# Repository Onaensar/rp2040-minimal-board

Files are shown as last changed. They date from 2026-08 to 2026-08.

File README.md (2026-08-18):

# ⚡ MDC RP2040 - Custom 4-Layer Development Board

A compact, industrial-standard 4-layer custom microcontroller development board powered by the **Raspberry Pi RP2040**. Built for high signal integrity, low-noise power distribution, and full hardware ESD protection.

---

## 📸 Hardware Overview

| Top View | Bottom View |
| :---: | :---: |
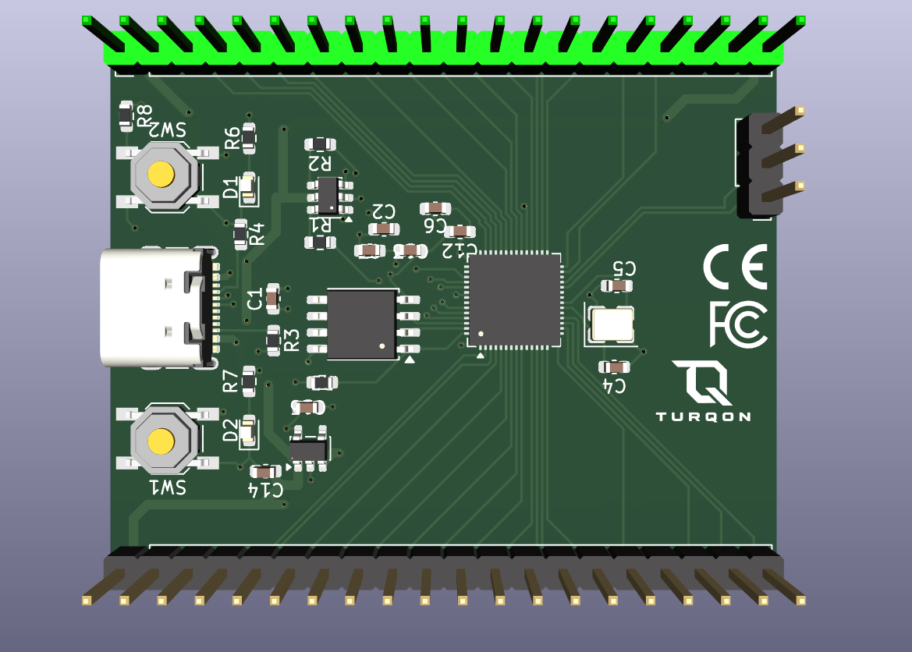
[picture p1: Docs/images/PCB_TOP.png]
Board Top
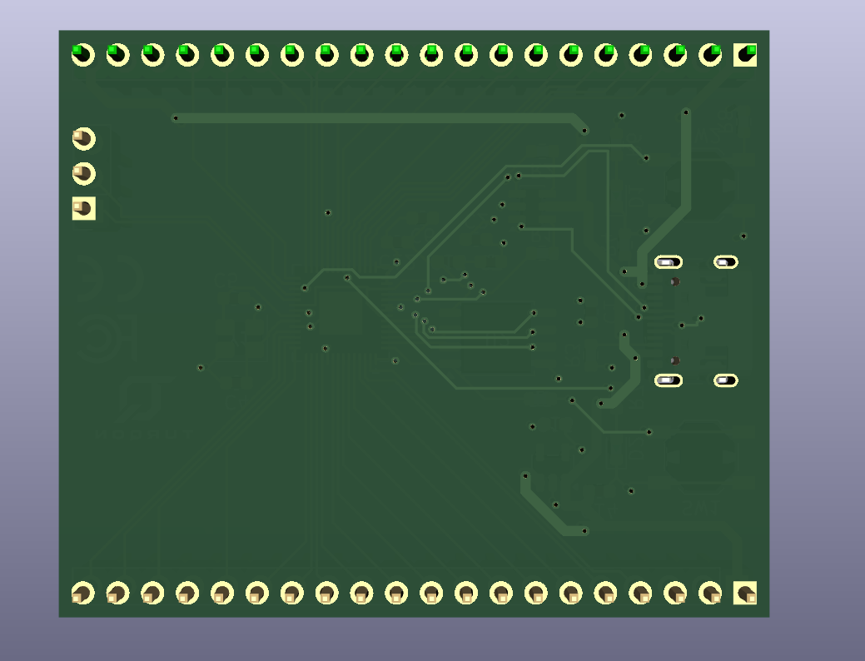
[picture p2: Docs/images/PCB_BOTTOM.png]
Board Bottom
|  |  |

---

## 🛠 Key Hardware Specifications

* **Microcontroller:** Raspberry Pi RP2040 (Dual ARM Cortex-M0+ @ 133 MHz, 264 KB SRAM)
* **Flash Memory:** 16 MB (128 Mb) Winbond QSPI Flash (`W25Q128JVSIQ`)
* **Power Regulation:**
  * High-performance 600 mA 3.3V LDO regulator (`AP2112K-3.3`)
  * Low ESR ceramic decoupling network across all internal power rails (`DVDD 1.1V`, `IOVDD 3.3V`, `ADC_AVDD 3.3V`)
* **USB Interface:** USB Type-C 2.0 with dedicated ESD protection (`USBLC6-2SC6`) and dual 5.1 kΩ CC configuration resistors
* **Clock System:** 12 MHz surface-mount crystal oscillator with dedicated symmetrical load capacitor array (`27 pF`) and isolated ground shielding
* **I/O & Peripherals:**
  * Standard 2.54 mm dual-row pinout exposing 30 multi-function GPIOs (SPI, I2C, UART, PWM, ADC)
  * Dedicated 3-pin SWD interface (`SWCLK`, `SWDIO`, `GND`) for debug probes (Picoprobe / J-Link)
  * Hardware `BOOT` and `RESET` pushbuttons
  * Status LEDs for `Power` (+3.3V) and user-programmable indicator (`GPIO25`)

---

## 📐 PCB Layer Stack-up (4-Layer FR-4)

Designed adhering to standard 1.6 mm PCB manufacturing guidelines (e.g., JLCPCB JLC04161H / PCBWay):

| Layer | Type | Copper Thickness | Function / Allocation |
| :--- | :--- | :--- | :--- |
| **Layer 1 (F.Cu)** | Signal | 1.0 oz (35 µm) | Core ICs, high-speed USB differential pairs, QSPI routing, and local decoupling loops |
| **Layer 2 (In1.Cu)** | Plane | 0.5 oz (17.5 µm) | **Unbroken Solid Ground Plane (GND)** for optimal return path and EMI shielding |
| **Layer 3 (In2.Cu)** | Power | 0.5 oz (17.5 µm) | Dedicated **+3.3V & +1.1V Power Planes** |
| **Layer 4 (B.Cu)** | Signal / GND | 1.0 oz (35 µm) | Low-speed signal breakout paths with unbroken ground copper pour |

---

## 📁 Repository Structure

```text
├── docs/                   # Renderings, hardware design schematics (PDF), and pinout guides
│   └── images/             # 3D PCB board renders
├── hardware/               # KiCad project files (.kicad_pro, .kicad_sch, .kicad_pcb)
├── manufacturing/          # Production-ready Gerbers, Drill files, BOM, and CPL files
├── .gitignore              # KiCad workspace exclusion rules
└── README.md

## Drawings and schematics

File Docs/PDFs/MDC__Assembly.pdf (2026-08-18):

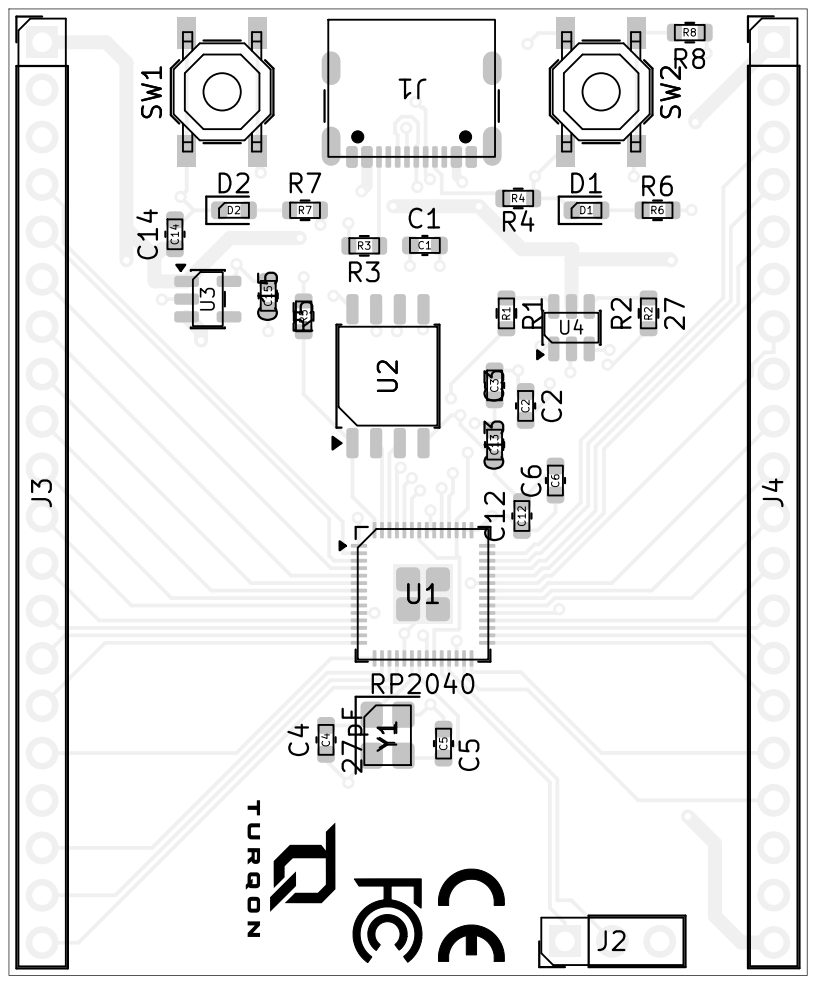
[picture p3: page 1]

MCU: RP2040 Dual ARM Cortex-M0+ | 16MB QSPI Flash
Architecture: 4-Layer FR-4 (JLC04161H Stackup)
Designed by: Abdullah Ensar Ön
TURQON
Sheet: Black And White TOP
File: MDC.kicad_pcb
Title: MDC RP2040 Minimal Dev Board
KiCad E.D.A. 10.0.4

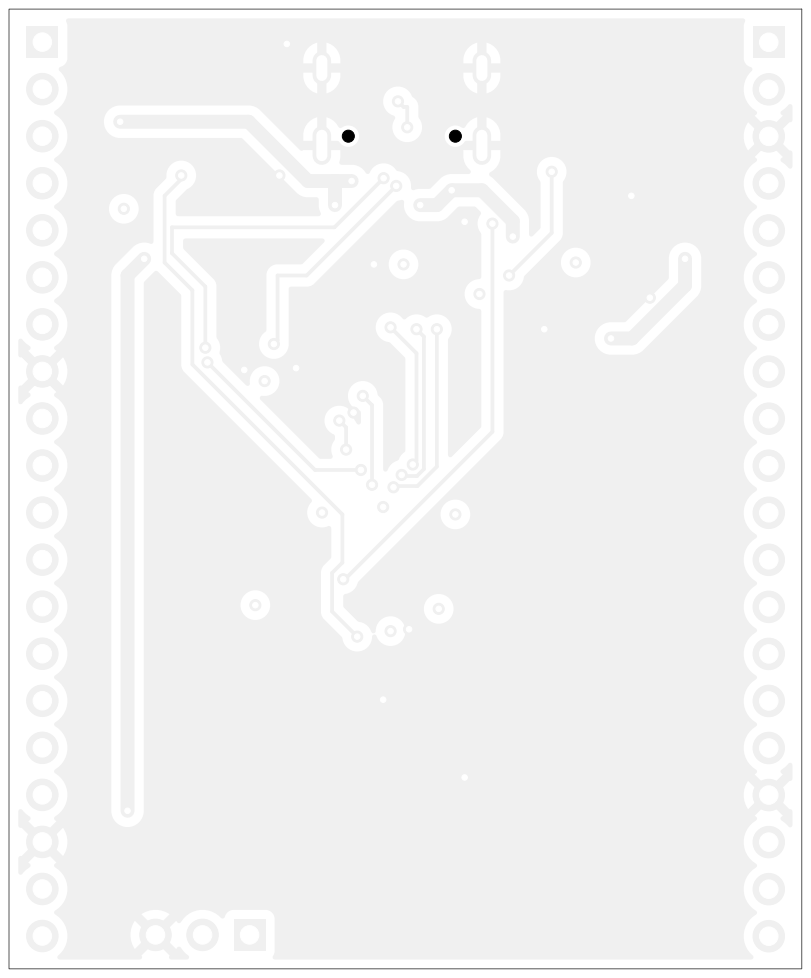
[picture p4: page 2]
D Date: 2026-08-18

Board2Pdf: Black And White BOT - Page 2/8
MCU: RP2040 Dual ARM Cortex-M0+ | 16MB QSPI Flash
Architecture: 4-Layer FR-4 (JLC04161H Stackup)
Designed by: Abdullah Ensar Ön
TURQON
Sheet: Black And White BOT
File: MDC.kicad_pcb
Title: MDC RP2040 Minimal Dev Board

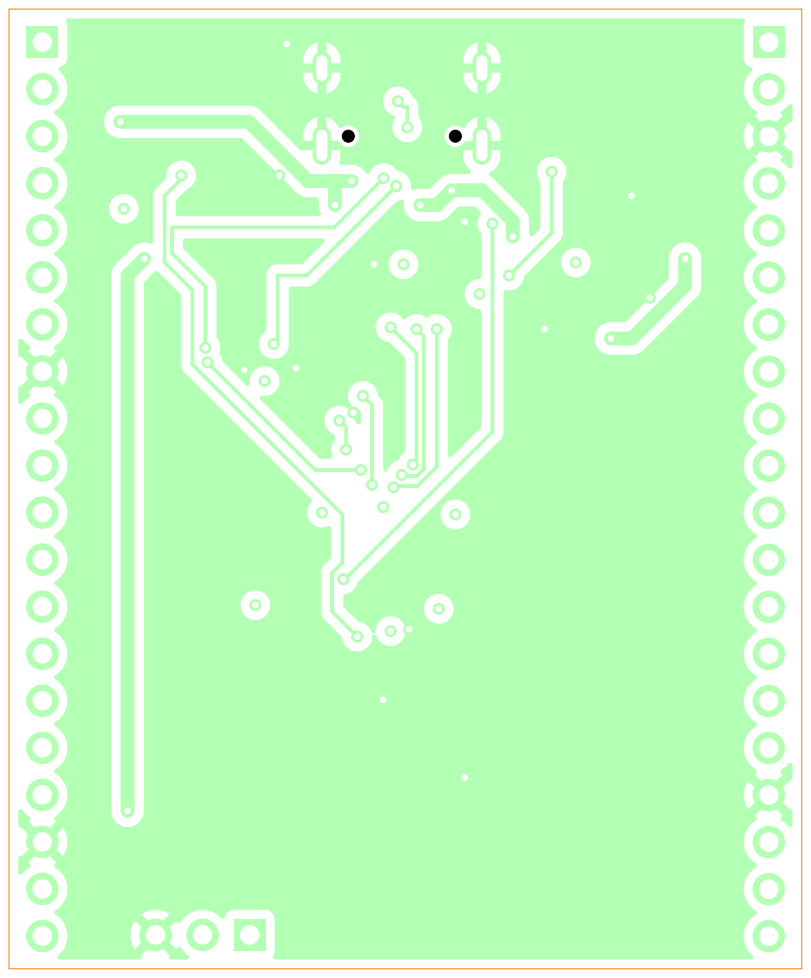
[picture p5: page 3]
D Date: 2026-08-18

Board2Pdf: Colored BOT - Page 3/8
MCU: RP2040 Dual ARM Cortex-M0+ | 16MB QSPI Flash
Architecture: 4-Layer FR-4 (JLC04161H Stackup)
Designed by: Abdullah Ensar Ön
TURQON
Sheet: Colored BOT
File: MDC.kicad_pcb
Title: MDC RP2040 Minimal Dev Board

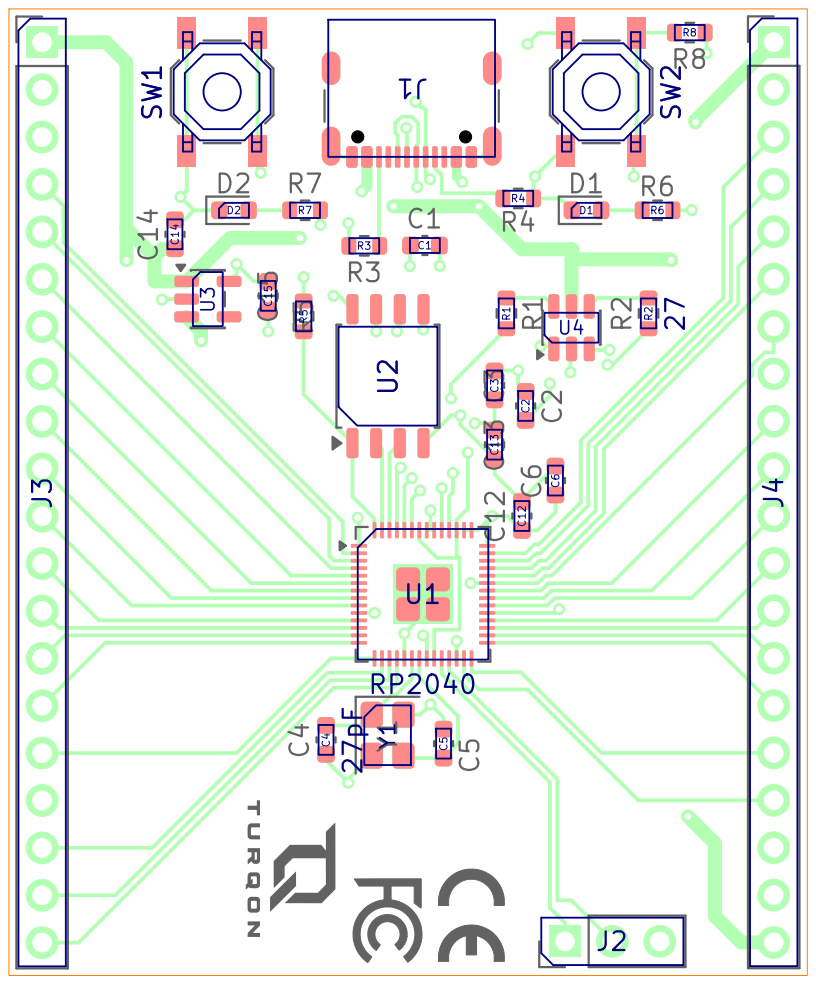
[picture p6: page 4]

MCU: RP2040 Dual ARM Cortex-M0+ | 16MB QSPI Flash
Architecture: 4-Layer FR-4 (JLC04161H Stackup)
Designed by: Abdullah Ensar Ön
TURQON
Sheet: Colored TOP
File: MDC.kicad_pcb
Title: MDC RP2040 Minimal Dev Board

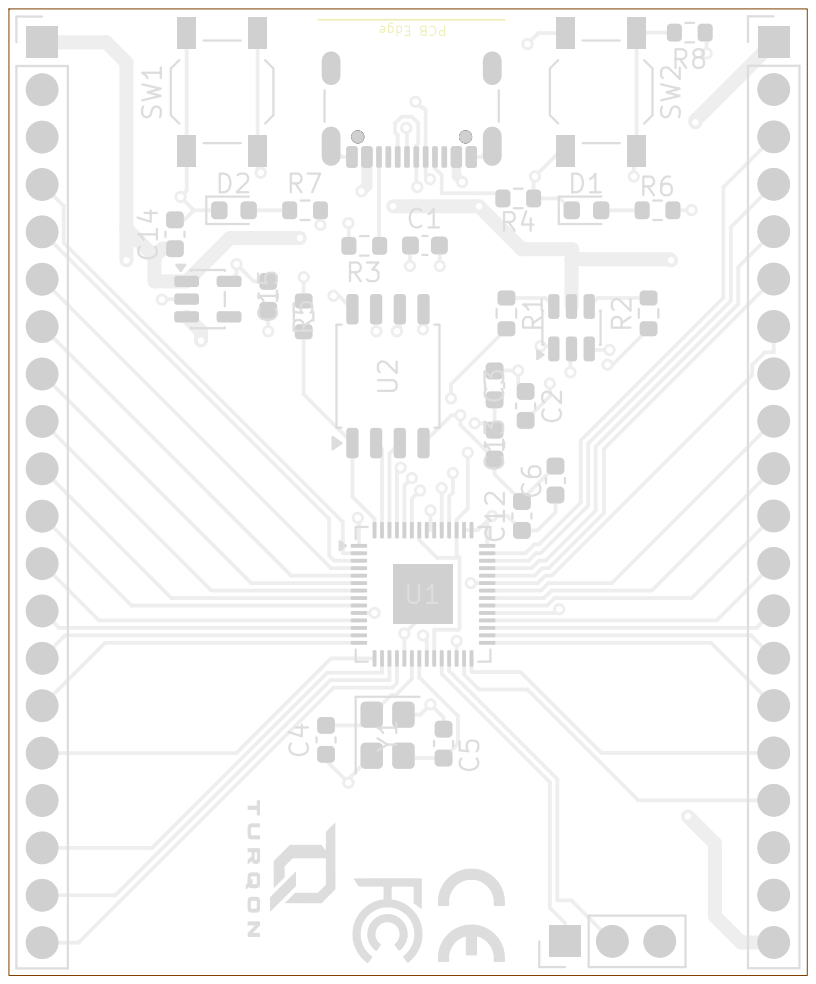
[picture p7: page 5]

Board2Pdf: Light Colors PCB Fabrication TOP - Page 5/8
MCU: RP2040 Dual ARM Cortex-M0+ | 16MB QSPI Flash
Architecture: 4-Layer FR-4 (JLC04161H Stackup)
Designed by: Abdullah Ensar Ön
TURQON
Sheet: Light Colors PCB Fabrication TOP
File: MDC.kicad_pcb
Title: MDC RP2040 Minimal Dev Board

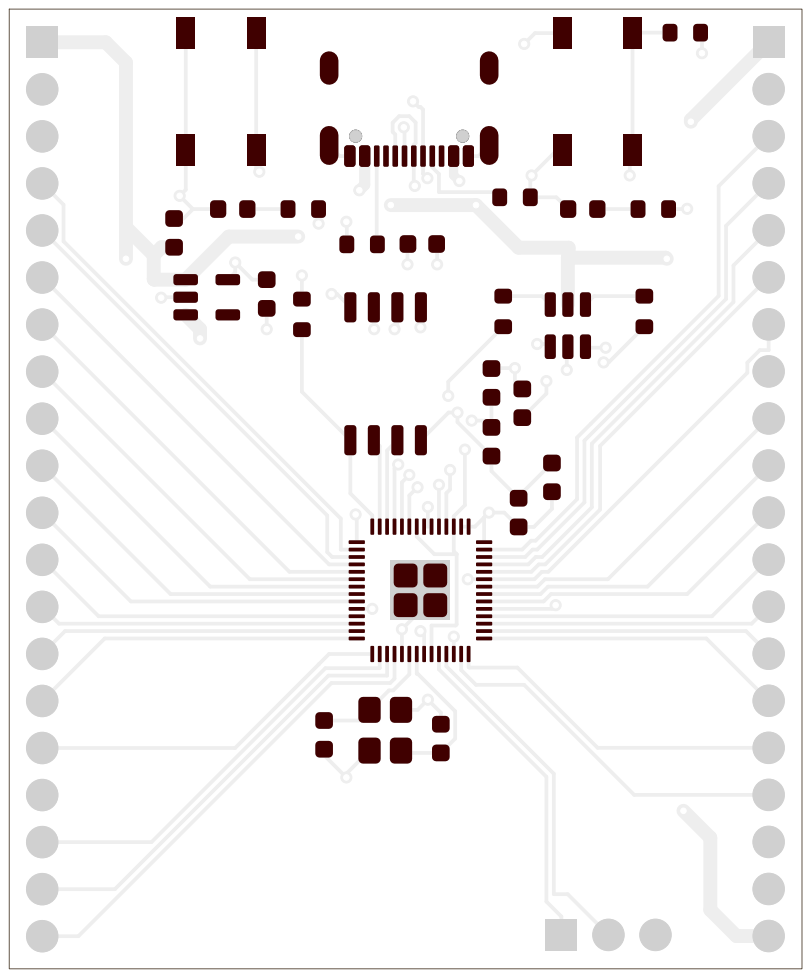
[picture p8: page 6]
D Date: 2026-08-18

Board2Pdf: Light Colors PCB Paste TOP - Page 6/8
MCU: RP2040 Dual ARM Cortex-M0+ | 16MB QSPI Flash
Architecture: 4-Layer FR-4 (JLC04161H Stackup)
Designed by: Abdullah Ensar Ön
TURQON
Sheet: Light Colors PCB Paste TOP
File: MDC.kicad_pcb
Title: MDC RP2040 Minimal Dev Board

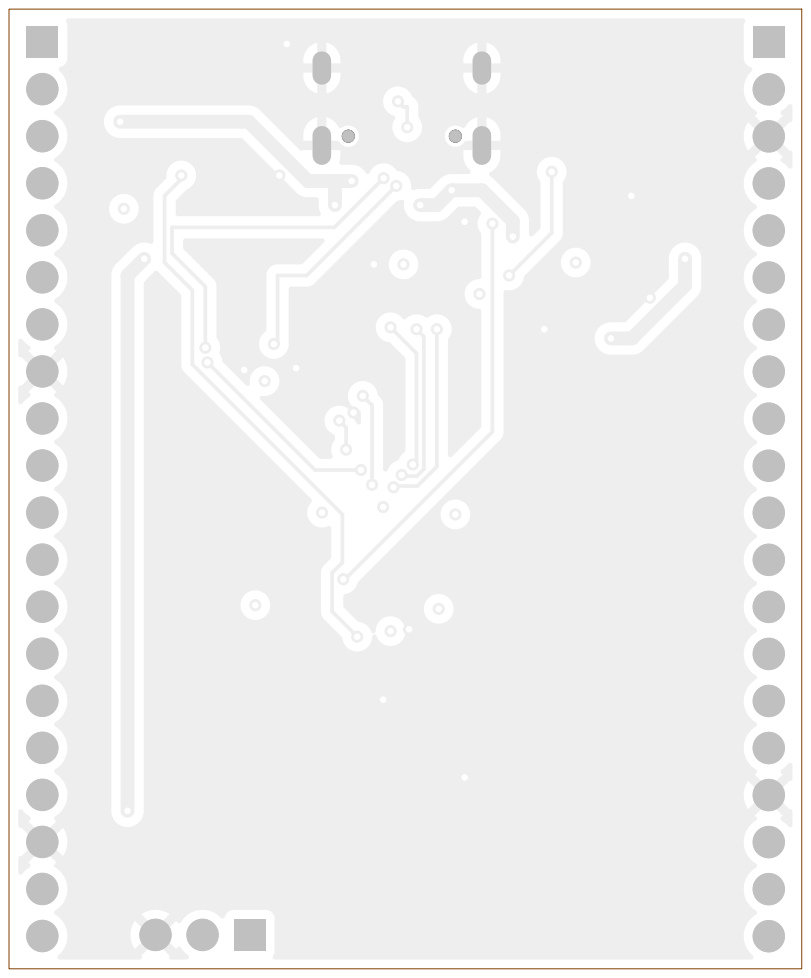
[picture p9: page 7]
D Date: 2026-08-18

Board2Pdf: Light Colors Placement BOT - Page 7/8
MCU: RP2040 Dual ARM Cortex-M0+ | 16MB QSPI Flash
Architecture: 4-Layer FR-4 (JLC04161H Stackup)
Designed by: Abdullah Ensar Ön
TURQON
Sheet: Light Colors Placement BOT
File: MDC.kicad_pcb
Title: MDC RP2040 Minimal Dev Board

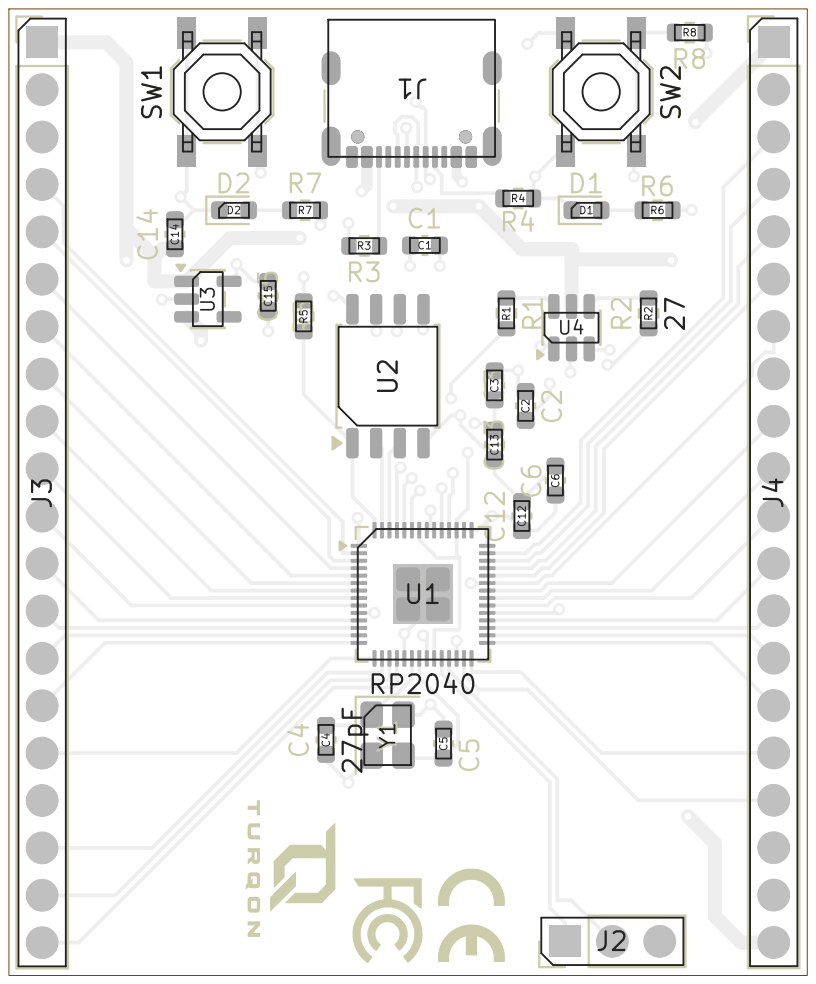
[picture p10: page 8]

Board2Pdf: Light Colors Placement TOP - Page 8/8
MCU: RP2040 Dual ARM Cortex-M0+ | 16MB QSPI Flash
Architecture: 4-Layer FR-4 (JLC04161H Stackup)
Designed by: Abdullah Ensar Ön
TURQON
Sheet: Light Colors Placement TOP
File: MDC.kicad_pcb
Title: MDC RP2040 Minimal Dev Board

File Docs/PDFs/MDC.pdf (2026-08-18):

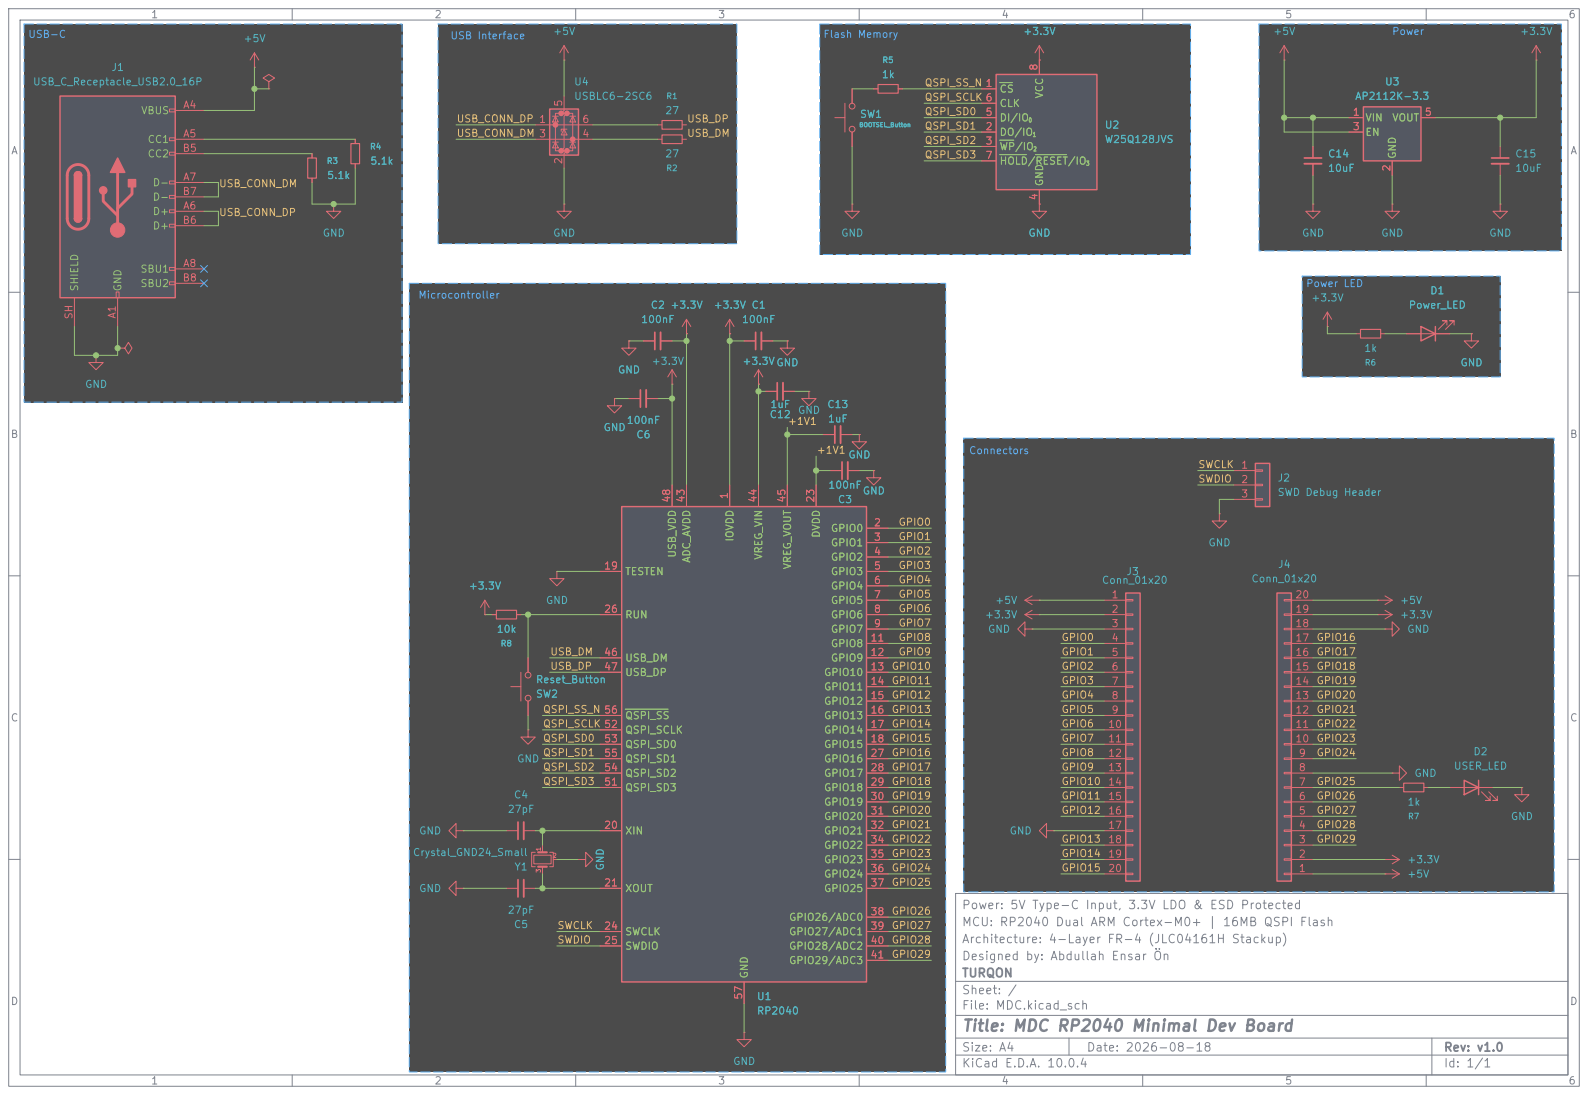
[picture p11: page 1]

4 DI/IO0 5 CLK 6 HOLD/RESET/IO3 7 VCC

MCU: RP2040 Dual ARM Cortex-M0+ | 16MB QSPI Flash
Architecture: 4-Layer FR-4 (JLC04161H Stackup)
Designed by: Abdullah Ensar Ön
TURQON
Sheet: /
File: MDC.kicad_sch
Title: MDC RP2040 Minimal Dev Board

Size: A4 | Rev: v1.0
KiCad E.D.A. 10.0.4 | Id: 1/1

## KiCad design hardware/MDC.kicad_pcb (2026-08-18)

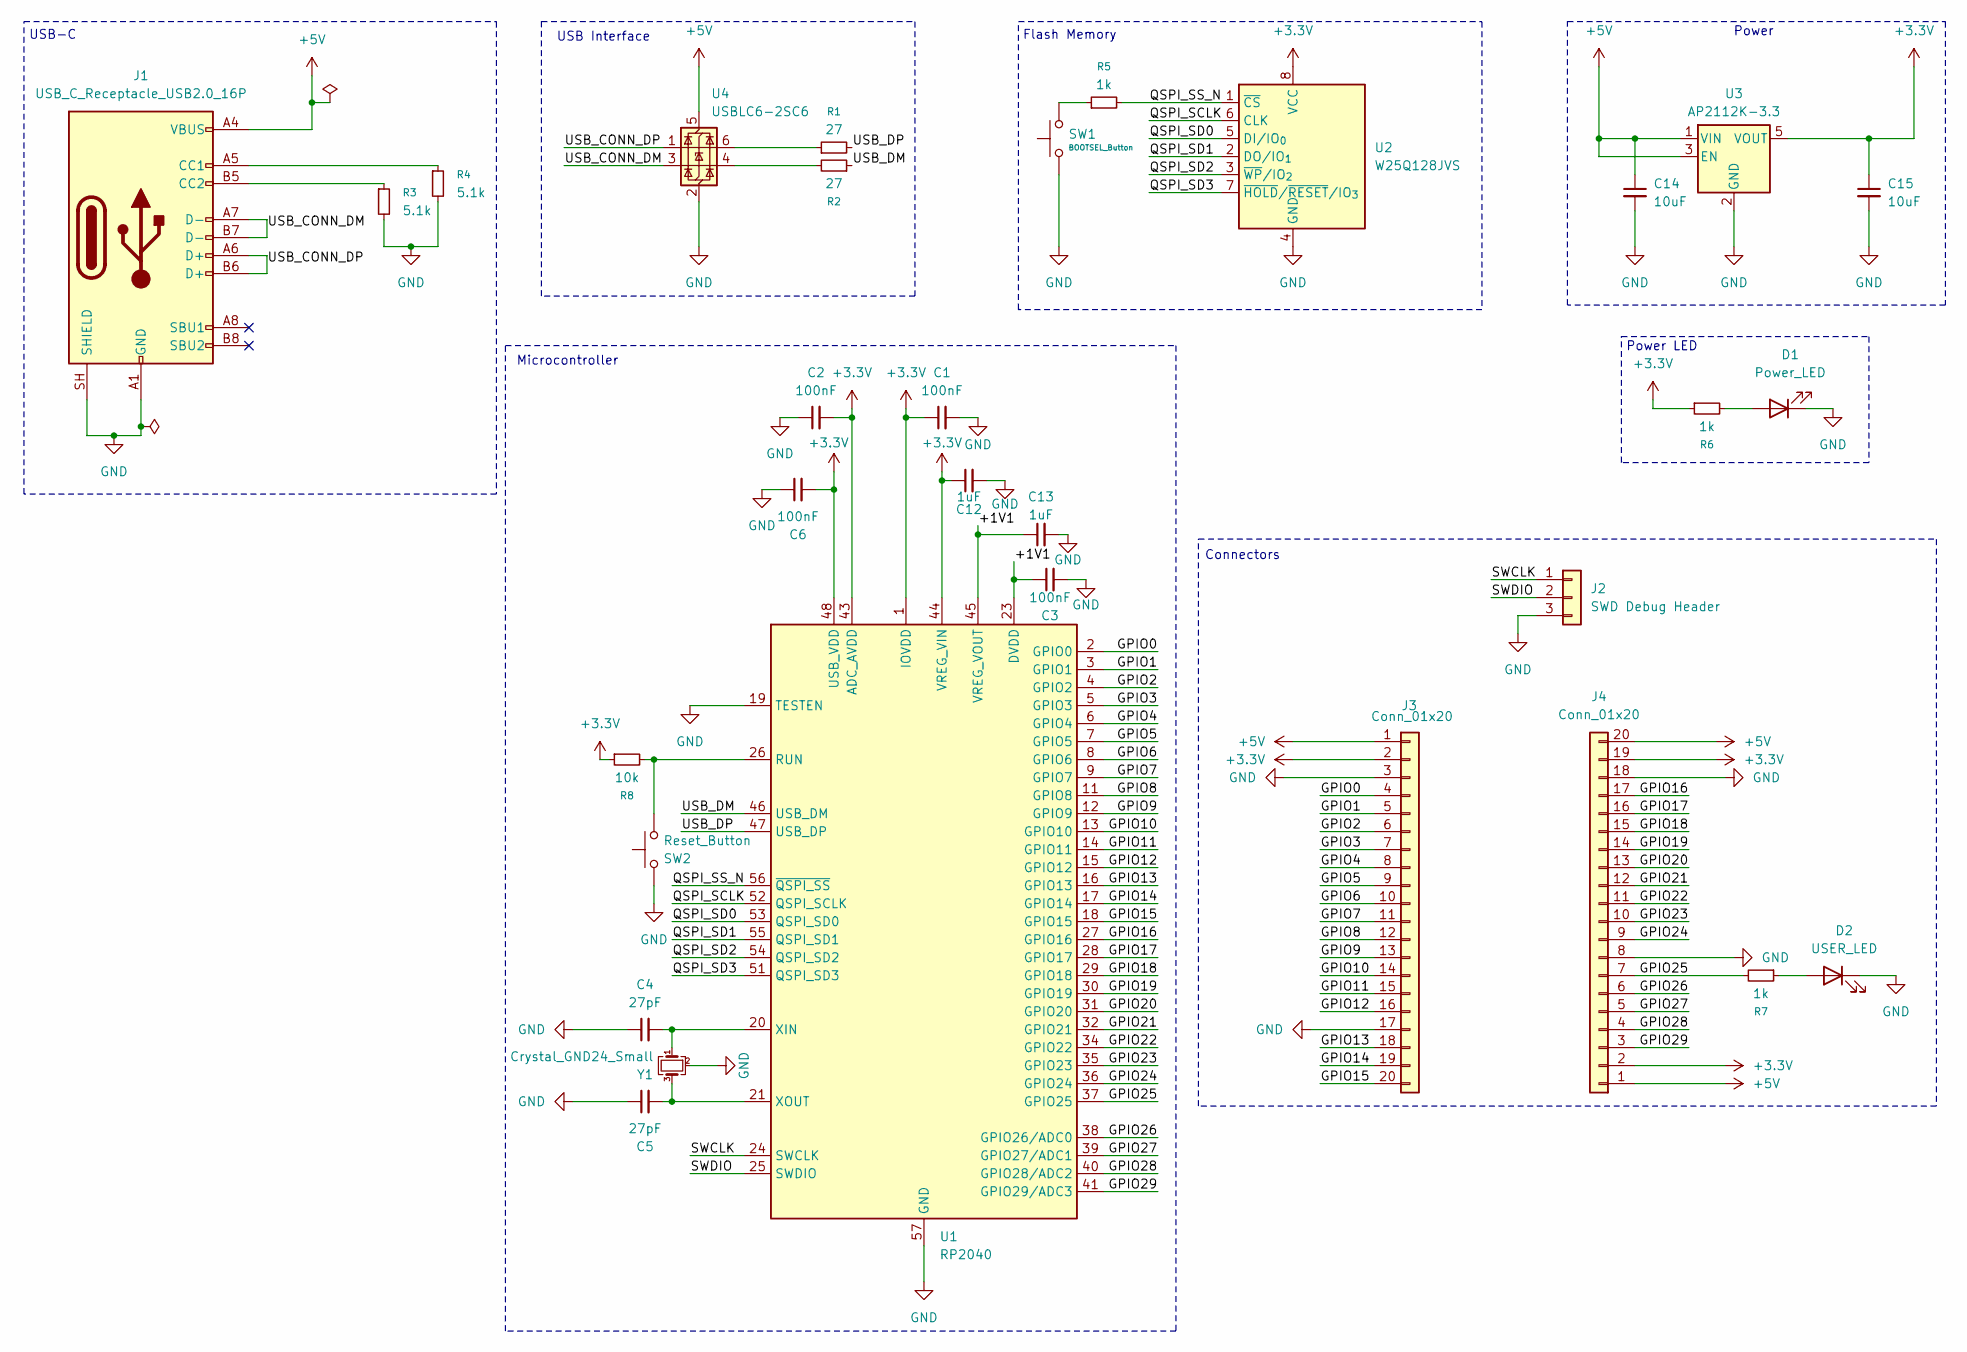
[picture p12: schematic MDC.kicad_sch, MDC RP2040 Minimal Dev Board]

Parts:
C1, C2, C3, C6: 100nF; C_0603_1608Metric
C4, C5: 27pF; C_0603_1608Metric
C12, C13: 1uF; C_0603_1608Metric
C14, C15: 10uF; C_0603_1608Metric
D1: Power_LED; LED_0603_1608Metric
D2: USER_LED; LED_0603_1608Metric
J1: USB_C_Receptacle_USB2.0_16P; USB_C_Receptacle_GCT_USB4105-xx-A_16P_TopMnt_Horizontal
J2: SWD Debug Header; PinHeader_1x03_P2.54mm_Vertical
J3, J4: Conn_01x20; PinHeader_1x20_P2.54mm_Vertical
R1, R2: 27; R_0603_1608Metric
R3, R4: 5.1k; R_0603_1608Metric
R5, R6, R7: 1k; R_0603_1608Metric
R8: 10k; R_0603_1608Metric
SW1: BOOTSEL_Button; SW_SPST_TL3342
SW2: Reset_Button; SW_SPST_TL3342
U1: RP2040; QFN-56-1EP_7x7mm_P0.4mm_EP3.2x3.2mm
U2: W25Q128JVS; SOIC-8_5.3x5.3mm_P1.27mm
U3: AP2112K-3.3; SOT-23-5
U4: USBLC6-2SC6; SOT-23-6
Y1: Crystal_GND24_Small; Crystal_SMD_3225-4Pin_3.2x2.5mm

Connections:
+3.3V: C1.1, C2.2, C6.2, C12.1, C15.1, J3.2, J4.2, J4.19, R6.1, R8.1, U1.1 (IOVDD), U1.10 (IOVDD), U1.22 (IOVDD), U1.33 (IOVDD), U1.42 (IOVDD), U1.43 (ADC_AVDD), U1.44 (VREG_VIN), U1.48 (USB_VDD), U1.49 (IOVDD), U2.8 (VCC), U3.5 (VOUT)
+5V: C14.1, J1.A4 (VBUS), J1.A9 (VBUS), J1.B4 (VBUS), J1.B9 (VBUS), J3.1, J4.1, J4.20, U3.1 (VIN), U3.3 (EN), U4.5 (VBUS)
/+1V1: C3.1, C13.1, U1.23 (DVDD), U1.45 (VREG_VOUT), U1.50 (DVDD)
/GPIO0: J3.4, U1.2 (GPIO0)
/GPIO1: J3.5, U1.3 (GPIO1)
/GPIO2: J3.6, U1.4 (GPIO2)
/GPIO3: J3.7, U1.5 (GPIO3)
/GPIO4: J3.8, U1.6 (GPIO4)
/GPIO5: J3.9, U1.7 (GPIO5)
/GPIO6: J3.10, U1.8 (GPIO6)
/GPIO7: J3.11, U1.9 (GPIO7)
/GPIO8: J3.12, U1.11 (GPIO8)
/GPIO9: J3.13, U1.12 (GPIO9)
/GPIO10: J3.14, U1.13 (GPIO10)
/GPIO11: J3.15, U1.14 (GPIO11)
/GPIO12: J3.16, U1.15 (GPIO12)
/GPIO13: J3.18, U1.16 (GPIO13)
/GPIO14: J3.19, U1.17 (GPIO14)
/GPIO15: J3.20, U1.18 (GPIO15)
/GPIO16: J4.17, U1.27 (GPIO16)
/GPIO17: J4.16, U1.28 (GPIO17)
/GPIO18: J4.15, U1.29 (GPIO18)
/GPIO19: J4.14, U1.30 (GPIO19)
/GPIO20: J4.13, U1.31 (GPIO20)
/GPIO21: J4.12, U1.32 (GPIO21)
/GPIO22: J4.11, U1.34 (GPIO22)
/GPIO23: J4.10, U1.35 (GPIO23)
/GPIO24: J4.9, U1.36 (GPIO24)
/GPIO25: J4.7, R7.2, U1.37 (GPIO25)
/GPIO26: J4.6, U1.38 (GPIO26/ADC0)
/GPIO27: J4.5, U1.39 (GPIO27/ADC1)
/GPIO28: J4.4, U1.40 (GPIO28/ADC2)
/GPIO29: J4.3, U1.41 (GPIO29/ADC3)
/QSPI_SCLK: U1.52 (QSPI_SCLK), U2.6 (CLK)
/QSPI_SD0: U1.53 (QSPI_SD0), U2.5 (DI/IO_{0})
/QSPI_SD1: U1.55 (QSPI_SD1), U2.2 (DO/IO_{1})
/QSPI_SD2: U1.54 (QSPI_SD2), U2.3 (~WP/IO_{2})
/QSPI_SD3: U1.51 (QSPI_SD3), U2.7 (~HOLD/~RESET/IO_{3})
/QSPI_SS_N: R5.2, U1.56 (~QSPI_SS), U2.1 (~CS)
/SWCLK: J2.1, U1.24 (SWCLK)
/SWDIO: J2.2, U1.25 (SWDIO)
/USB_CONN_DM: J1.A7 (D-), J1.B7 (D-), U4.3 (I/O2)
/USB_CONN_DP: J1.A6 (D+), J1.B6 (D+), U4.1 (I/O1)
/USB_DM: R2.1, U1.46 (USB_DM)
/USB_DP: R1.2, U1.47 (USB_DP)
GND: C1.2, C2.1, C3.2, C4.1, C5.1, C6.1, C12.2, C13.2, C14.2, C15.2, D1.1 (K), D2.1 (K), J1.A1 (GND), J1.A12 (GND), J1.B1 (GND), J1.B12 (GND), J1.SH (SHIELD), J2.3, J3.3, J3.17, J4.8, J4.18, R3.2, R4.2, SW1.1, SW2.2, U1.19 (TESTEN), U1.57 (GND), U2.4 (GND), U3.2 (GND), U4.2 (GND), Y1.2 (G), Y1.4 (G)
unnamed: D1.2 (A), R6.2
unnamed: D2.2 (A), R7.1
unnamed: J1.A5 (CC1), R4.1
unnamed: J1.B5 (CC2), R3.1
unnamed: R1.1, U4.6 (I/O1)
unnamed: R2.2, U4.4 (I/O2)
unnamed: R5.1, SW1.2
unnamed: R8.2, SW2.1, U1.26 (RUN)
unnamed: C4.2, U1.20 (XIN), Y1.1
unnamed: C5.2, U1.21 (XOUT), Y1.3

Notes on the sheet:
Power
Connectors
Flash Memory
USB-C
Power LED
Microcontroller
USB Interface

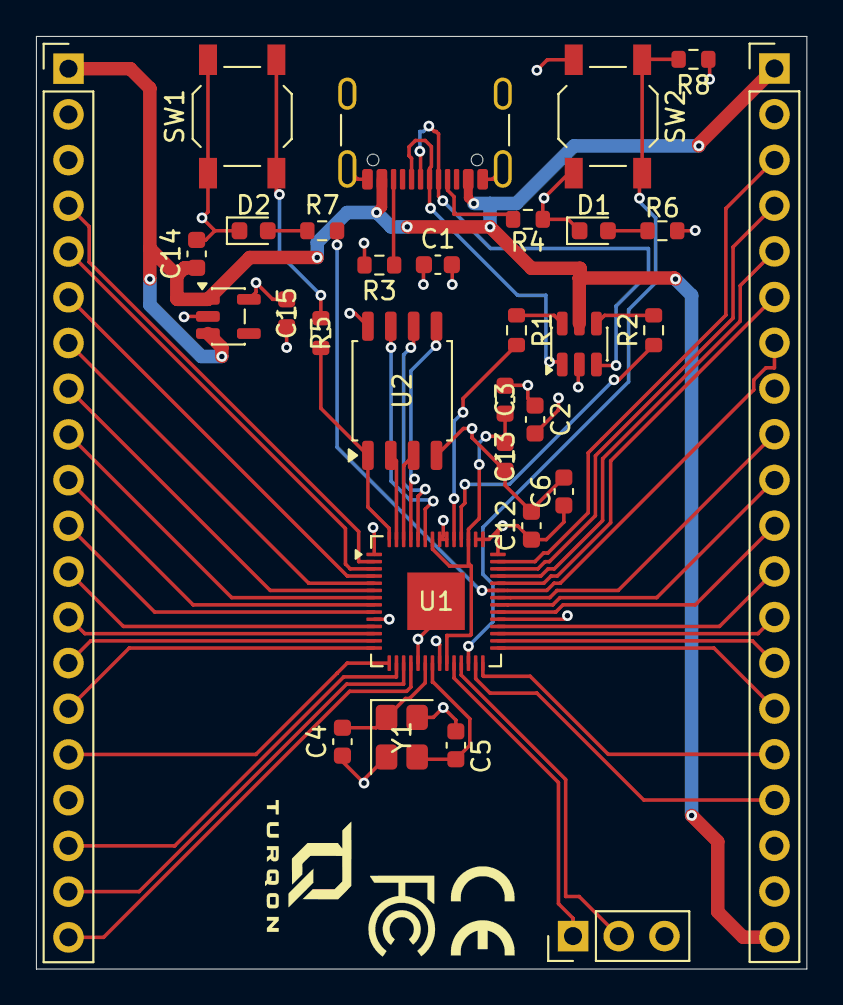
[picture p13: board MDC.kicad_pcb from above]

Board: 4 copper layers, 42.8 x 51.8 mm, 31 parts (0 on the bottom side), 56 nets.

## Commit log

2026-08-18 Initial commit: RP2040 4-layer custom minimal dev board
    [MDC-B_Cu.gbr, MDC-B_Mask.gbr, MDC-B_Paste.gbr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]
2026-08-18 Refactor: Klasör yapısı düzenlendi ve gereksiz dosyalar silindi
    [connectors.kicad_sch]
2026-08-18 Değişiklik
    [MDC.kicad_pcb, MDC.kicad_sch]
2026-08-18 Chore: MDC-backups klasörü git takibinden çıkarıldı
    [MDC.kicad_pcb, MDC.kicad_sch]
